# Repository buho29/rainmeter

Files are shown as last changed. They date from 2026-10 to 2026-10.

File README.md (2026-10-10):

# Zigbee Tipping Bucket Rain Gauge for Home Assistant

> 🇪🇸 [Versión en español](README%20es.md)
>
> 🖨️ **Download the print files on [MakerWorld](https://makerworld.com/es/models/3406401-rainmeter-zigbee-rain-gauge-for-home-assistant)**

A DIY tipping bucket rain gauge in Fusion 360, printed in ASA and read by a **Zigbee door sensor** (magnet + reed switch) integrated into Home Assistant. It shares its frame with a **Stevenson screen** that shelters a temperature, humidity and pressure sensor, and it has a plate rain sensor on the side.

<p align="center">
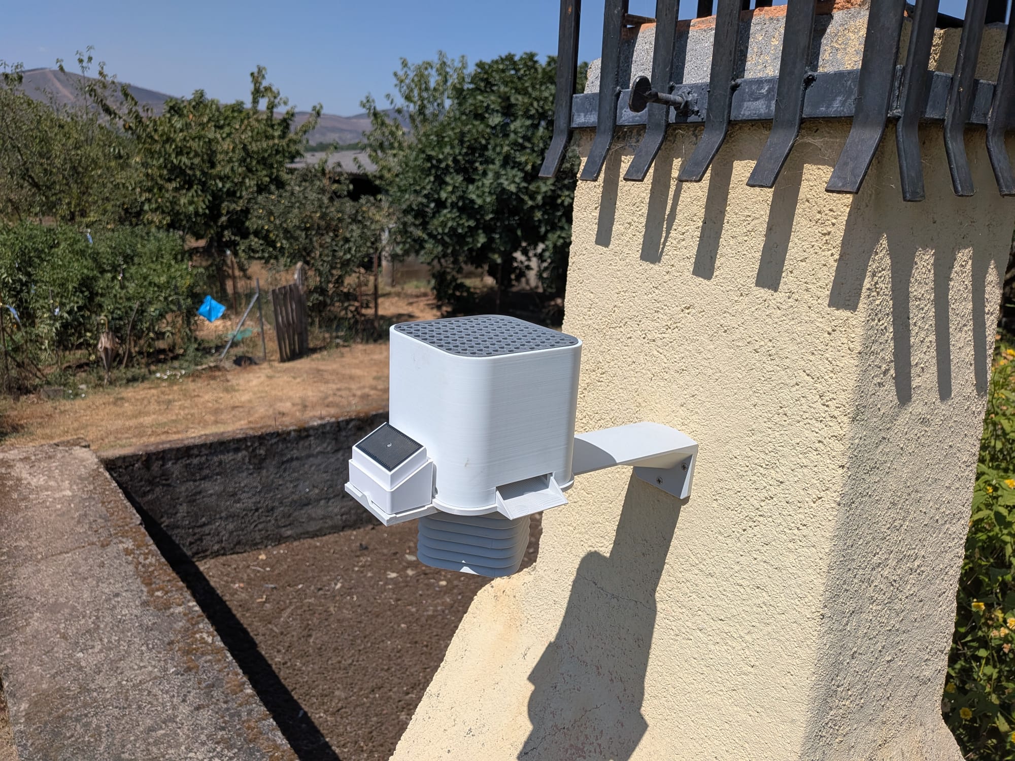
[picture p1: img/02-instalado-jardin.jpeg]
Installed rain gauge
  
</p>

## Features

| Parameter | Value |
|---|---|
| Collection area | **100 cm²** (square opening with R20 mm corners, side ≈ 101.7 mm) |
| Volume per tip | **5 ml** → **0.5 mm** of rain |
| Tip sensor | Zigbee door sensor (`binary_sensor.puerta_1_contact`), no ESP needed |
| Material | ASA (UV and weather resistant) |
| Bucket axle | Ø2.5 mm stainless steel, seated directly in the ASA |
| End stops | M3 screws threaded into the part, they set the tipping angle |
| Magnet | Ø3 × 2 mm neodymium magnet on the tipping bucket, triggers the door sensor's reed switch |
| Extras | Stevenson screen, plate rain sensor, storm warning |

## Zigbee sensors used

| | Sensor | Purpose | Link |
|---|---|---|---|
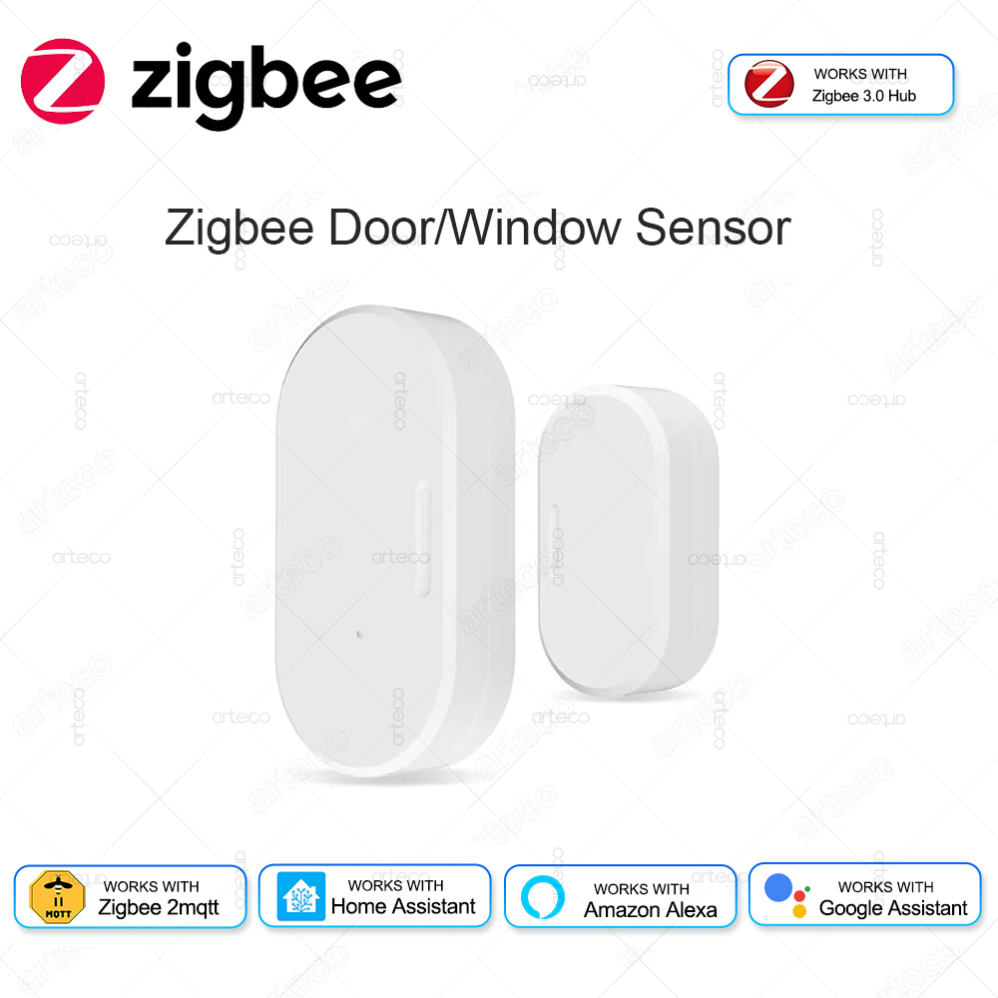
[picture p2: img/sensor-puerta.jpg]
Door sensor
|  | Door sensor (reed) | Counts the bucket tips | [AliExpress](https://es.aliexpress.com/item/1005007307128850.html) |
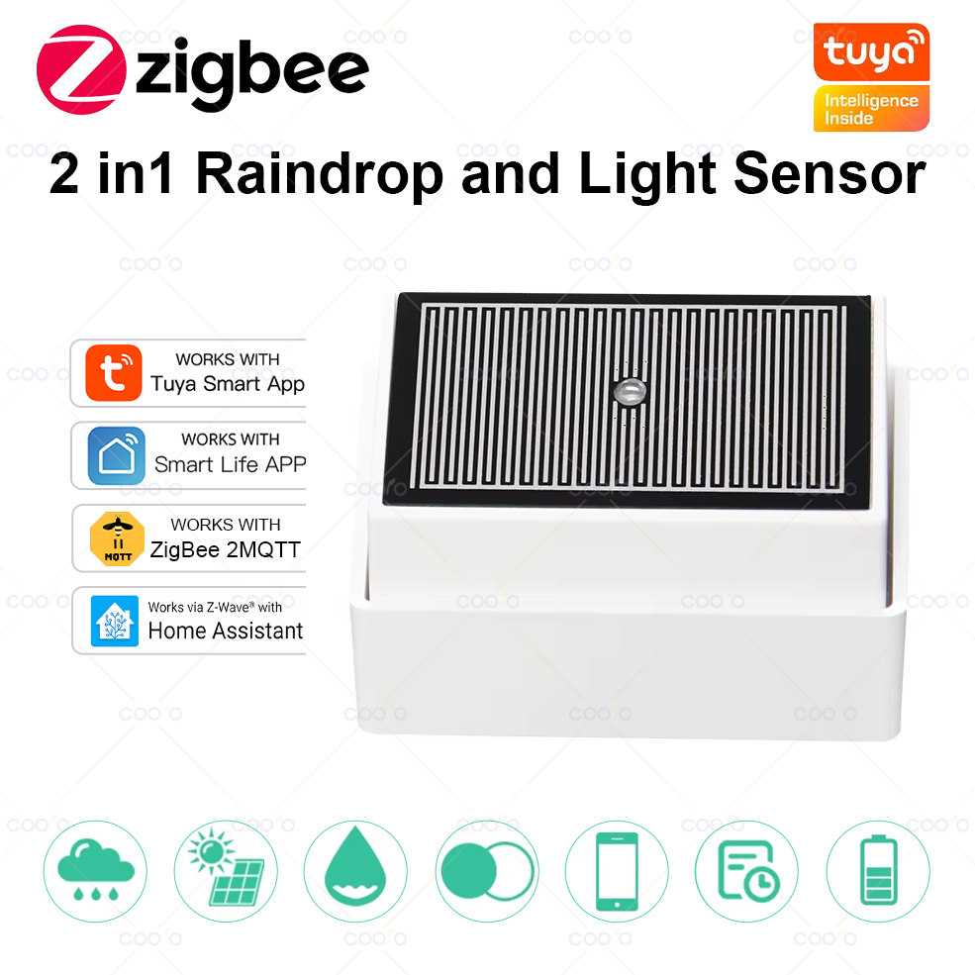
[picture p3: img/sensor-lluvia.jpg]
Rain sensor
|  | Plate rain + light sensor (Tuya) | Detects rain and measures illuminance | [AliExpress](https://es.aliexpress.com/item/1005009511764724.html) ⚠️ **not recommended** |
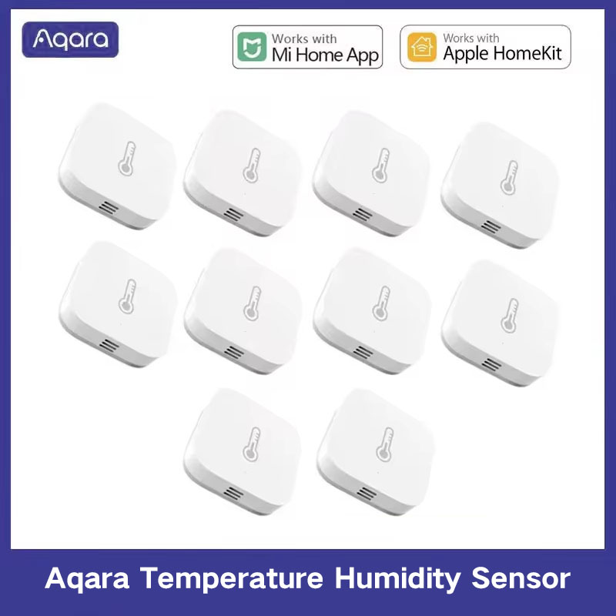
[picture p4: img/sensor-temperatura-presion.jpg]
Aqara sensor
|  | Aqara temperature / humidity / pressure | Inside the Stevenson screen | [AliExpress](https://es.aliexpress.com/item/1005007499860935.html) |

## Files

| File | Description |
|---|---|
| [MakerWorld](https://makerworld.com/es/models/3406401-rainmeter-zigbee-rain-gauge-for-home-assistant) | Published model, ready to print |
| [`rainmeter.yaml`](rainmeter.yaml) | Home Assistant package: counters, rain/flow sensors, `utility_meter`, pressure trend and storm warning |
| [`dashboard.yaml`](dashboard.yaml) | Weather station dashboard card |
| [`embudo.3mf`](embudo.3mf) | Print project (Bambu Studio) |
| [`3D source/`](3D%20source/) | Model sources: `pluviometro.f3z` (Fusion 360) and `pluviometro.step` |

## Home Assistant installation

1. In `configuration.yaml`:

   ```yaml
   homeassistant:
     packages: !include_dir_named packages
   ```

2. Copy `rainmeter.yaml` to `<config>/packages/rainmeter.yaml`.
3. Change the `entity_id`s to match your hardware (`binary_sensor.puerta_1_contact`, `sensor.termometro_exterior_pressure`).
4. Restart HA (or reload `counter`, `input_datetime` and `template`; `utility_meter` needs a restart).
5. Paste `dashboard.yaml` into a manual card. It uses custom cards from HACS (`mushroom`, `mini-graph-card`, `expander-card`, `card-mod`).

### Main entities

| Entity | Description |
|---|---|
| `counter.rainmeter_tip_count_calibration` | Tips in the calibration session (reset by hand) |
| `counter.rainmeter_tip_count_total` | Total tips (never reset, feeds the `utility_meter`s) |
| `sensor.rainmeter_rain_accumulated` | Rain accumulated in the session (mm) |
| `sensor.rainmeter_flow_rate` | Average flow over the session (mL/s) |
| `sensor.rainmeter_rain_rate_hourly` | Rain in the current hour (mm/h) |
| `sensor.rainmeter_rain_rate_daily` | Rain in the current day (mm/24h) |
| `sensor.rainmeter_pressure_trend` | Pressure trend (hPa/h) |

### Conversions

- Tips → mm: `tips × 0.5`
- mm → mL (100 cm²): `mm × 10`
- mL/s → mm/h (100 cm²): `mL/s × 360`

## Calibrating the end-stop screws

You need a 5 ml syringe and a 100 ml measure.

> **Level the rain gauge before calibrating.** If it is tilted, one side tips earlier than the other and the calibration is wrong.

### 1. Adjust each side (4.6 ml)
1. Let the bucket rest on one side.
2. With the syringe, slowly add **4.6 ml** to the upper bucket.
3. Adjust the M3 end-stop screw on that side until the bucket tips right at 4.6 ml. If it tips too early or too late, turn the screw and repeat.
4. Do the same on the other side.

It is calibrated at 4.6 ml instead of 5 ml for two reasons:
- Water keeps coming in while the bucket is tipping.
- A few drops always stay stuck in the bucket after each tip. The design tries to minimise them, but they never go away completely.

Together, each tip ends up being about 5 ml, which is what `rainmeter.yaml` counts.

### 2. Validate with 100 ml
1. Reset the counter with the **Resetear contador** (reset counter) button on the dashboard (`counter.rainmeter_tip_count_calibration`).
2. Pour **100 ml very slowly** into the gauge opening.
3. It should read **20 tips** (accumulated = 10 mm).
4. The **Flujo** (flow) sensor (`sensor.rainmeter_flow_rate`) must not go above **6 ml/s**. At 12 ml/s about 15 % is lost (see [Flow test](#flow-test)).

If you get more than 20 tips, each tip holds less than 5 ml: adjust the stops so it tips with a little more water. If you get fewer, do the opposite. Repeat until you get 20.

### 3. Check again in the final installation
Once it is mounted in place, level it again and use the syringe to check that each side still tips at 4.6 ml, or at whatever volume worked in the 100 ml test. Screwing on the bracket can leave it slightly tilted and shift the tipping point. If one side has changed, readjust its end-stop screw.

## Design notes

### Tipping bucket
- Double V-shaped bucket (1.6 mm wall) on a **Ø2.5 mm stainless steel axle**, with **M3 screw end stops** threaded into the part that set the tipping angle.
- Calibration target, the same one `rainmeter.yaml` uses: **5 ml per tip = 0.5 mm** of rain over 100 cm².
- **Axle height:** higher = cleaner tip but needs more angle; very low = "twitchy" tipping.
- **Chamfer** towards the axle: moves the water's centre of gravity away and makes it tip earlier. Bucket **depth** was the most effective lever to increase volume.
- Balance at the tipping point: `m_water · d_water = m_body · d_body` (water centre of gravity measured in Fusion with *Boundary Fill*).
- With little angular travel after tipping, drops stay trapped; at ~20° hardly any remain.

### Water inlet
- The central wedge was removed: it catapulted the water out. It is better for water to fall into the corner of the bucket.
- Wide-mesh leaf guard (fine meshes splash and clog).

### Asymmetric counting (solved)
When tipping to one side it counted twice, and to the other side once (or not at all). It was not software: the sensor was not centred relative to the two magnet positions. **Moving the sensor 13 mm** fixed it.

That is why `rainmeter.yaml` has **no debounce**. The `Rainmeter - Increment tip counters` automation fires on every `off → on` change of `binary_sensor.puerta_1_contact`, adds one to both counters and uses `mode: queued` so quick consecutive tips are not lost.

### Flow test
Measured with `sensor.rainmeter_flow_rate`, which computes `(tips × 5) / seconds`. The seconds run from the first tip of the session (`input_datetime.rainmeter_flow_start_time`) to the last one. It is an average flow meant for calibration, not an instantaneous rain rate. To convert to mm/h: `mL/s × 360`.

- 6 ml/s (≈ 2160 mm/h) → correct reading (200 ml out of 200 ml).
- 12 ml/s (≈ 4320 mm/h) → ~15 % loss.
- Both are far above any real rainfall (records are around 300 mm/h over 1 min).

### Storm warning
A `derivative` sensor (`sensor.rainmeter_pressure_trend`, 20 min window) computes the pressure trend in hPa/h from `sensor.termometro_exterior_pressure`. The `Rainmeter - Storm Warning` automation:

- Fires when the trend drops below **−3 hPa/h** (storm approaching) or rises above **+3 hPa/h** (gust front already arriving), held for **2 min**.
- Has a **90 min cooldown**, so the pressure recovering after a spike does not count as a new storm.
- Sends `notify.notify` and a `persistent_notification` with a fixed `notification_id` (it updates instead of piling up).

**Why a 20 min window:** the derivative was simulated over 10 days of pressure history, including the storm on 03/10/2026. With 30 min the trend barely reached +3.2 hPa/h and did not hold for 2 min, so it **would not have warned**. With 20 min it would have warned about 14 min before the heavy rain, with no false alarms in those 10 days. With 15 min or less, the sensor's 0.1 hPa steps already cause false alarms.

### Zigbee sensor care
- Door sensors are not waterproof: keep the reed switch and magnet away from water.
- Zigbee latency and battery drain during very heavy rain.

## Gallery

### Installed

<table>
  <tr>
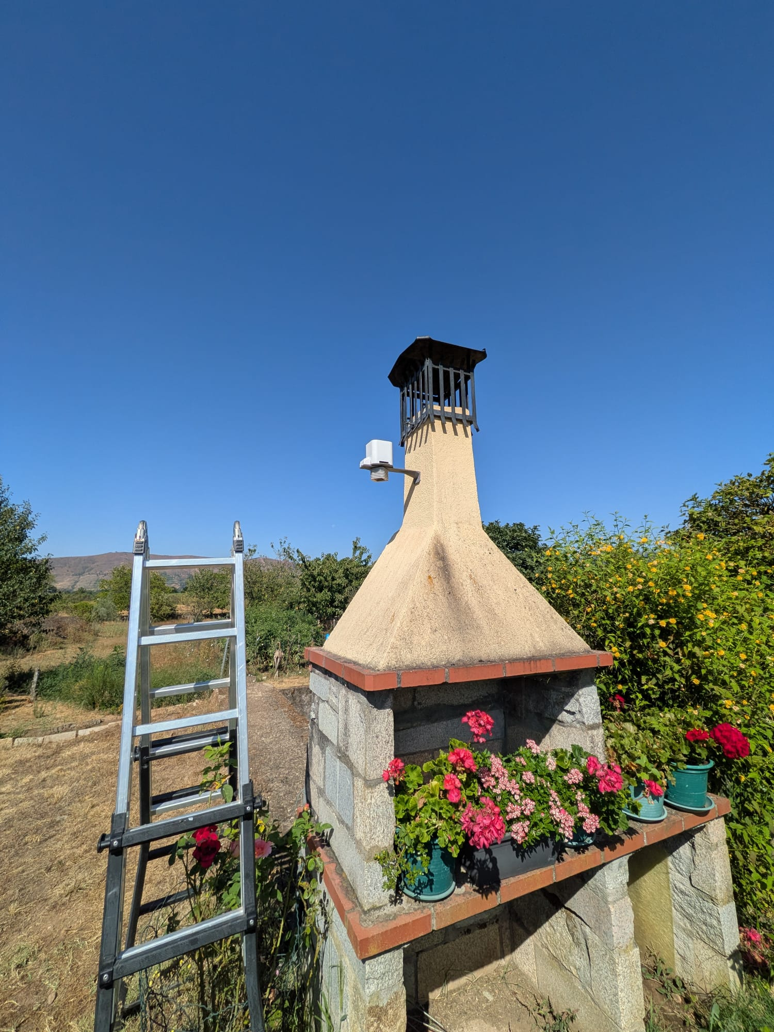
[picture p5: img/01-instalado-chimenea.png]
Installed on the chimney
    <td></td>
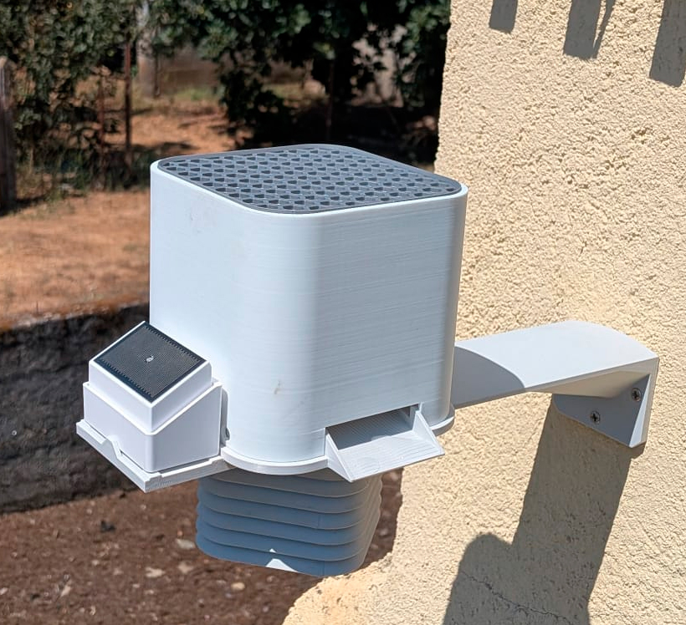
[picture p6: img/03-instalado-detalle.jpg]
Installed, close-up
    <td></td>
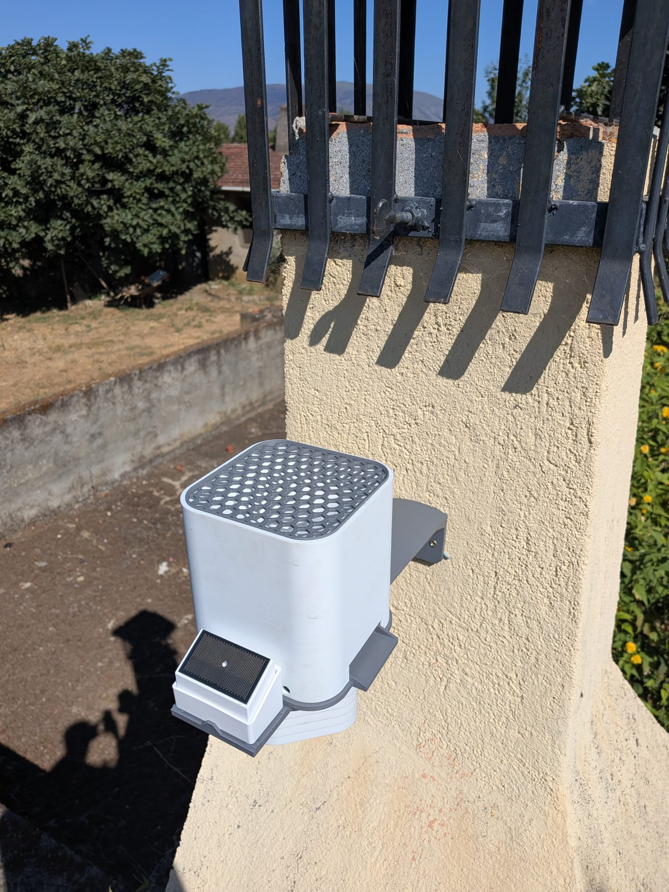
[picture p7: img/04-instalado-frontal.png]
View from above
    <td></td>
  </tr>
  <tr>
    <td align="center" valign="top" width="33%">Overview</td>
    <td align="center" valign="top" width="33%">Close-up</td>
    <td align="center" valign="top" width="33%">View from above</td>
  </tr>
  <tr>
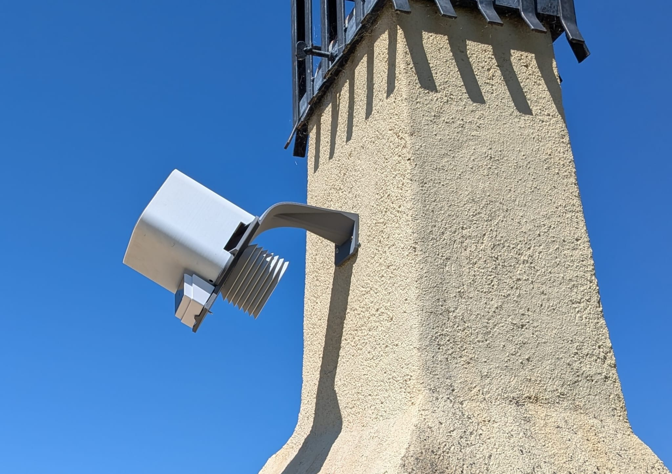
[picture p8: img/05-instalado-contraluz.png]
From below
    <td></td>
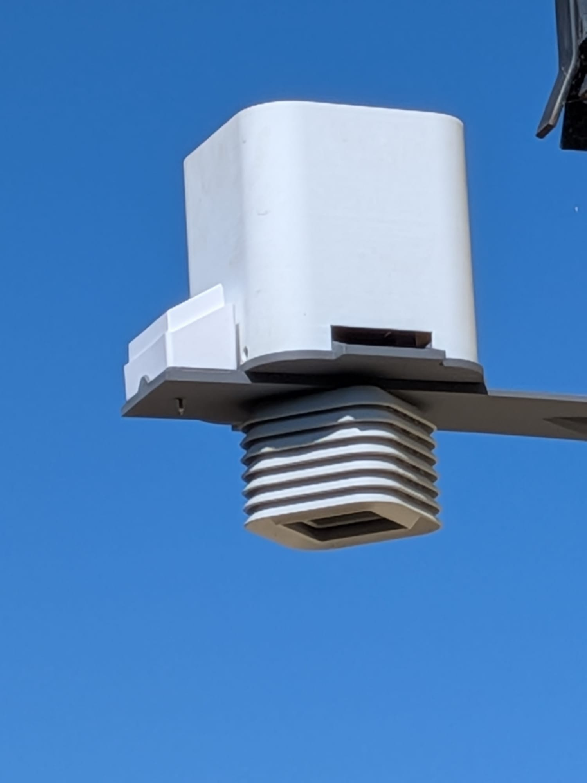
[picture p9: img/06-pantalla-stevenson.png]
Stevenson screen
    <td></td>
    <td>Installed</td>
  </tr>
  <tr>
    <td align="center" valign="top" width="33%">From below<br><sub>The arm in this version was printed in PLA and didn't last even 3 h in the sun</sub></td>
    <td align="center" valign="top" width="33%">Stevenson screen</td>
    <td align="center" valign="top" width="33%">Installed</td>
  </tr>
</table>

### Assembly

<table>
  <tr>
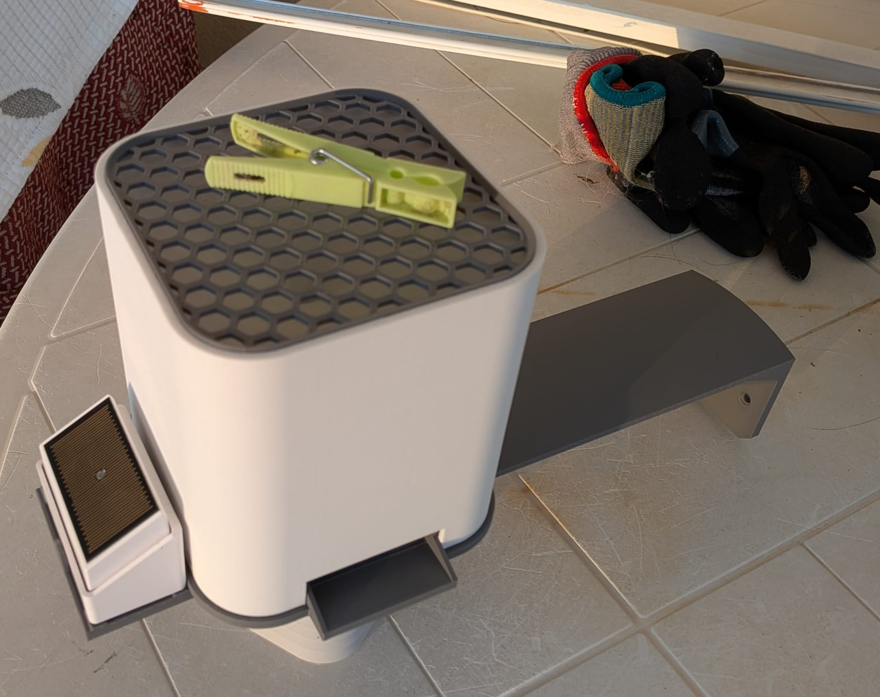
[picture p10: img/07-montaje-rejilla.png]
Leaf guard
    <td></td>
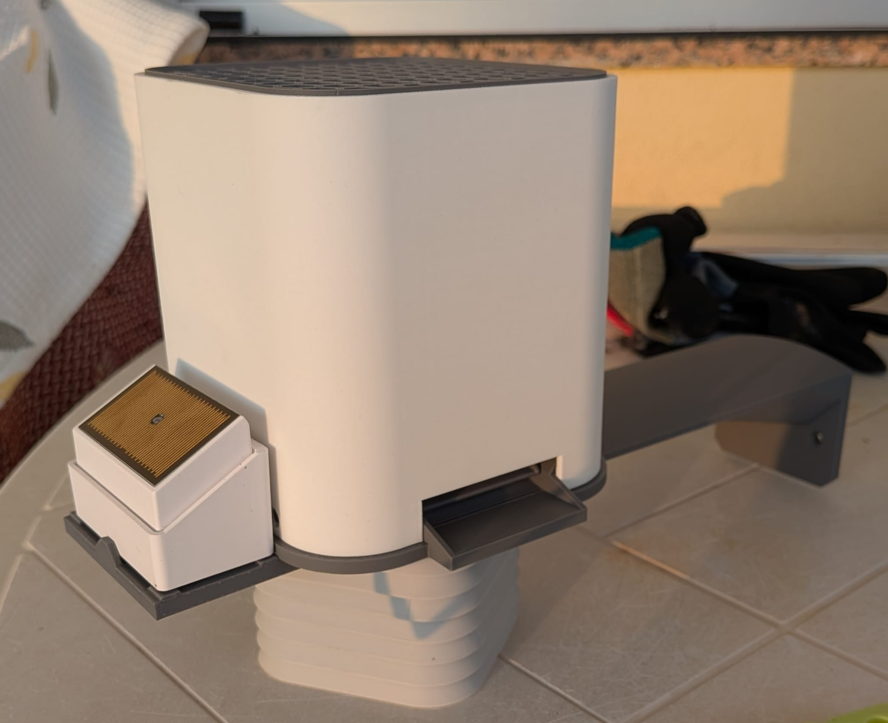
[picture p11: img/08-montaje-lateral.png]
Side view
    <td></td>
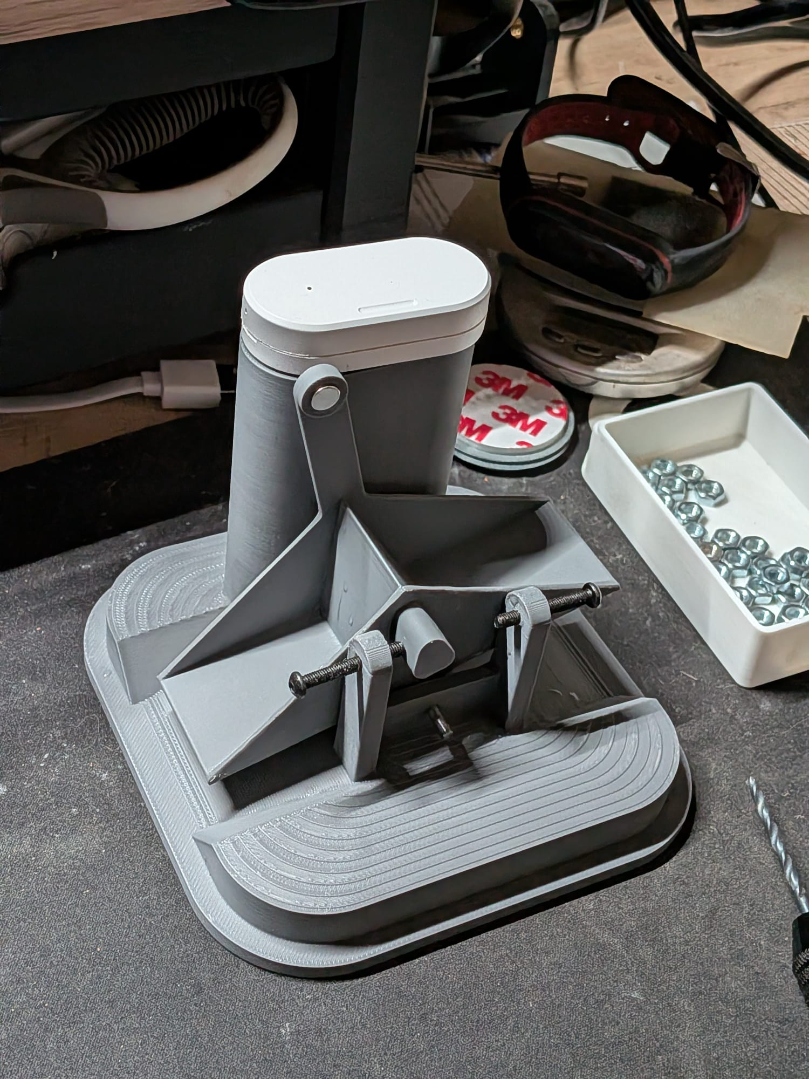
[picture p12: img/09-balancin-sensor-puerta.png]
Tipping bucket and door sensor
    <td></td>
  </tr>
  <tr>
    <td align="center">Leaf guard</td>
    <td align="center">Side view</td>
    <td align="center">Tipping bucket, end stops and door sensor</td>
  </tr>
</table>

### 3D design (Fusion 360)

<table>
  <tr>
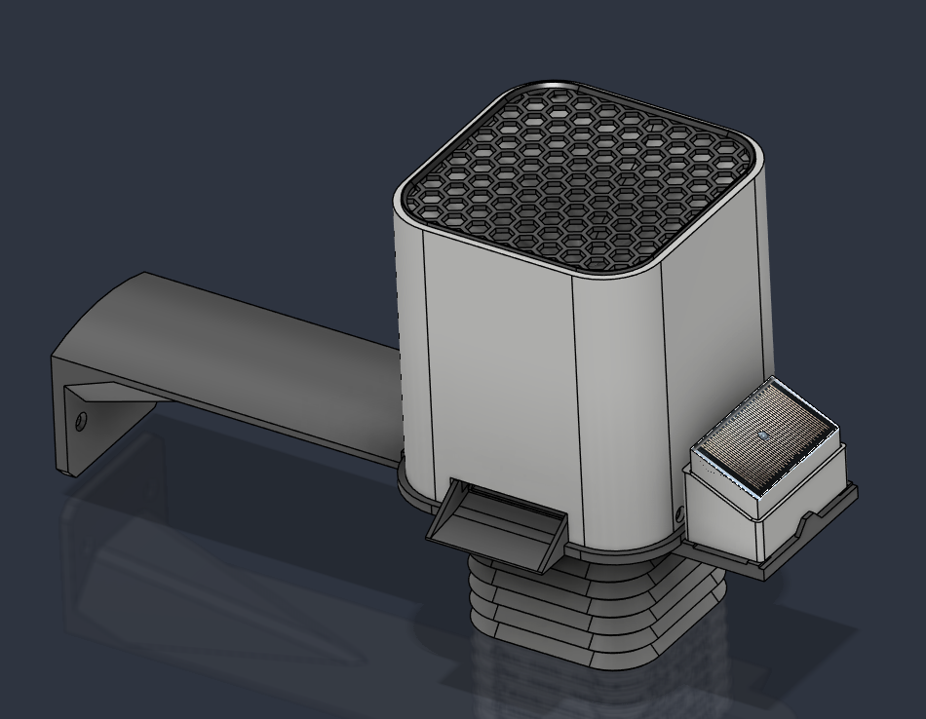
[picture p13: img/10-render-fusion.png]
Full render
    <td></td>
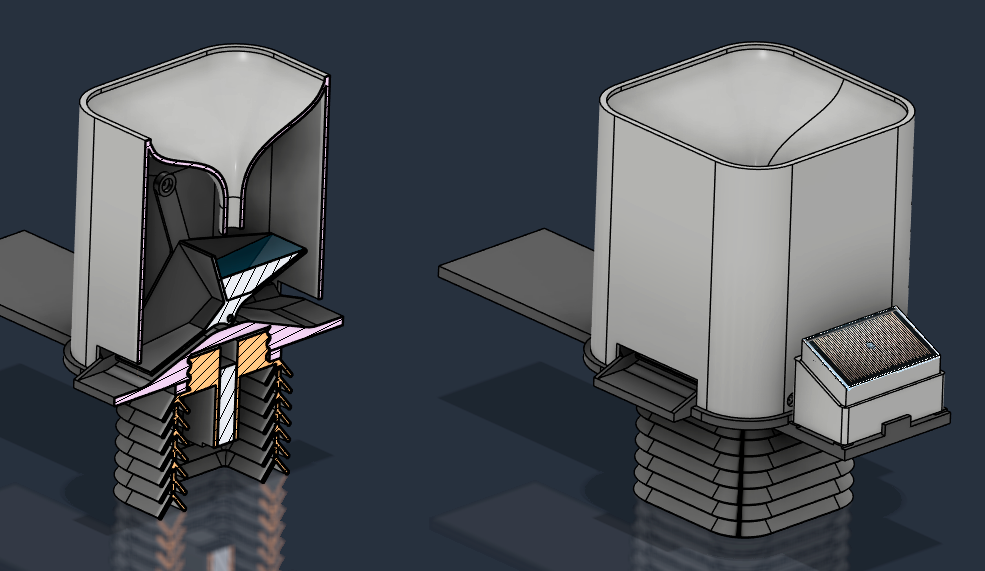
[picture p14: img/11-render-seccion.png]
Funnel and bucket cross-section
    <td></td>
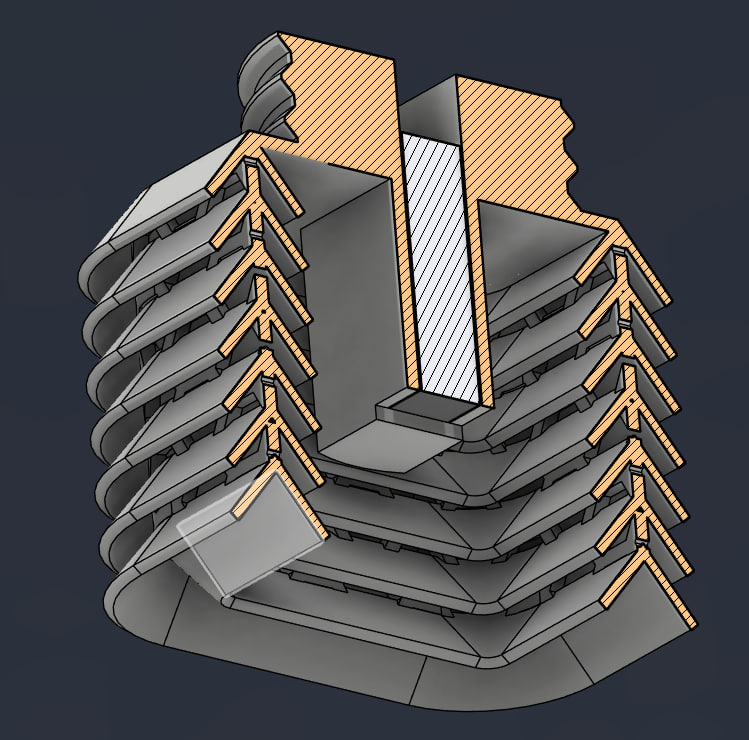
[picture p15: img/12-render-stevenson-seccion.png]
Stevenson screen cross-section
    <td></td>
  </tr>
  <tr>
    <td align="center">Full render</td>
    <td align="center">Cross-section: funnel and bucket</td>
    <td align="center">Cross-section: Stevenson screen</td>
  </tr>
</table>

### Home Assistant

<p align="center">
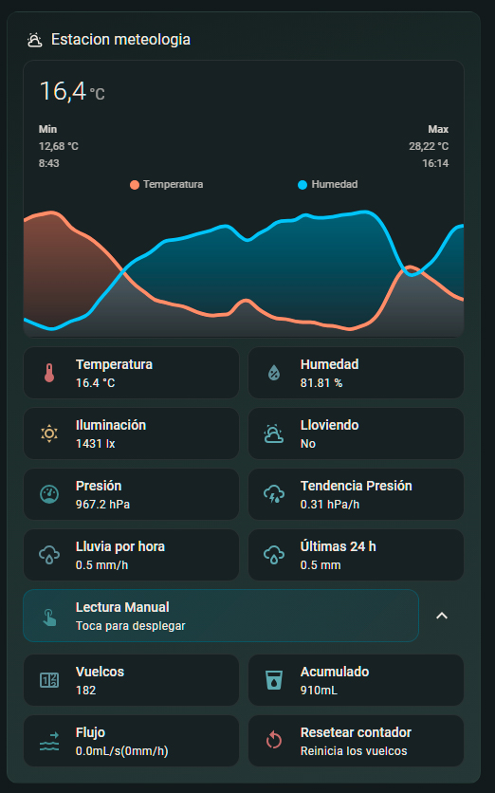
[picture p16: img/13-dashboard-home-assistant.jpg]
Home Assistant dashboard
  
</p>

## Sources of inspiration

- **Thread:** [Fusion 360 Thread Profiles for 3D Printing](https://makerworld.com/es/models/2567099-fusion-360-thread-profiles-for-3d-printing#profileId-2829308). Thread profiles for Fusion 360 tuned for 3D printing.
- [Rain Gauge](https://makerworld.com/es/models/1366151-rain-gauge): the idea of an adjustable tipping bucket with calibration screws came from here.
- [Tipping Bucket Rain Gauge](https://makerworld.com/es/models/1451114-tipping-bucket-rain-gauge): 100 cm² rain gauge with 5 ml per tip (0.5 mm).
- [LTB Weather Station](https://www.thingiverse.com/thing:2849562) (Thingiverse): 3D-printable weather station.

This rain gauge is an original design; these models were used only as reference.

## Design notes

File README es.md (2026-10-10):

# Pluviómetro basculante Zigbee para Home Assistant

> 🇬🇧 [English version](README.md)
>
> 🖨️ **Descarga los archivos de impresión en [MakerWorld](https://makerworld.com/es/models/3406401-rainmeter-zigbee-rain-gauge-for-home-assistant)**

Pluviómetro DIY de balancín (*tipping bucket*) diseñado en Fusion 360, impreso en ASA y leído con un **sensor de puerta Zigbee** (imán + reed) integrado en Home Assistant. Comparte estructura con una **pantalla Stevenson** que protege un sensor de temperatura, humedad y presión, y lleva un sensor de lluvia de placa en el lateral.

<p align="center">
  Pluviómetro instalado
</p>

## Características

| Parámetro | Valor |
|---|---|
| Área de captación | **100 cm²** (boca cuadrada R20 mm, lado ≈ 101,7 mm) |
| Volumen por vuelco | **5 ml** → **0,5 mm** de lluvia |
| Sensor de vuelcos | Sensor de puerta Zigbee (`binary_sensor.puerta_1_contact`), sin ESP |
| Material | ASA (resistente a UV e intemperie) |
| Eje del balancín | Acero inoxidable Ø2,5 mm alojado directamente en el ASA |
| Topes | Tornillos M3 que se atornillan en la pieza y regulan el ángulo de disparo |
| Imán | Imán de neodimio de Ø3 × 2 mm en el balancín, activa el reed del sensor de puerta |
| Extras | Pantalla Stevenson, sensor de lluvia de placa, alerta de tormenta |

## Sensores Zigbee usados

| | Sensor | Uso | Enlace |
|---|---|---|---|
| Sensor de puerta | Sensor de puerta (reed) | Cuenta los vuelcos del balancín | [AliExpress](https://es.aliexpress.com/item/1005007307128850.html) |
| Sensor de lluvia | Sensor de lluvia de placa + luz (Tuya) | Detecta lluvia y mide la iluminación | [AliExpress](https://es.aliexpress.com/item/1005009511764724.html) ⚠️ **no lo recomiendo** |
| Sensor Aqara | Aqara temperatura / humedad / presión | Dentro de la pantalla Stevenson | [AliExpress](https://es.aliexpress.com/item/1005007499860935.html) |

## Archivos

| Archivo | Descripción |
|---|---|
| [MakerWorld](https://makerworld.com/es/models/3406401-rainmeter-zigbee-rain-gauge-for-home-assistant) | Modelo publicado, listo para imprimir |
| [`rainmeter.yaml`](rainmeter.yaml) | *Package* de Home Assistant: contadores, sensores de lluvia/flujo, `utility_meter`, tendencia de presión y alerta de tormenta |
| [`dashboard.yaml`](dashboard.yaml) | Tarjeta de dashboard de la estación meteorológica |
| [`embudo.3mf`](embudo.3mf) | Proyecto de impresión (Bambu Studio) |
| [`3D source/`](3D%20source/) | Fuentes del modelo: `pluviometro.f3z` (Fusion 360) y `pluviometro.step` |

## Instalación en Home Assistant

1. En `configuration.yaml`:

   ```yaml
   homeassistant:
     packages: !include_dir_named packages
   ```

2. Copia `rainmeter.yaml` a `<config>/packages/rainmeter.yaml`.
3. Ajusta los `entity_id` a tu hardware (`binary_sensor.puerta_1_contact`, `sensor.termometro_exterior_pressure`).
4. Reinicia HA (o recarga `counter`, `input_datetime` y `template`; `utility_meter` necesita reinicio).
5. Pega `dashboard.yaml` en una tarjeta manual. Usa tarjetas personalizadas de HACS (`mushroom`, `mini-graph-card`, `expander-card`, `card-mod`).

### Entidades principales

| Entidad | Descripción |
|---|---|
| `counter.rainmeter_tip_count_calibration` | Vuelcos de la sesión de calibración (se resetea a mano) |
| `counter.rainmeter_tip_count_total` | Vuelcos totales (nunca se resetea, alimenta los `utility_meter`) |
| `sensor.rainmeter_rain_accumulated` | Lluvia acumulada en la sesión (mm) |
| `sensor.rainmeter_flow_rate` | Flujo medio de la sesión (mL/s) |
| `sensor.rainmeter_rain_rate_hourly` | Lluvia de la hora actual (mm/h) |
| `sensor.rainmeter_rain_rate_daily` | Lluvia del día actual (mm/24h) |
| `sensor.rainmeter_pressure_trend` | Tendencia de presión (hPa/h) |

### Conversiones

- Vuelcos → mm: `vuelcos × 0,5`
- mm → mL (100 cm²): `mm × 10`
- mL/s → mm/h (100 cm²): `mL/s × 360`

## Calibración de los tornillos de tope

Necesitas una jeringuilla de 5 ml y una medida de 100 ml.

> **Nivela el pluviómetro antes de calibrar.** Si está inclinado, un lado vuelca antes que el otro y la calibración no vale.

### 1. Ajustar cada lado (4,6 ml)
1. Deja el balancín apoyado en un lado.
2. Con la jeringuilla, echa **4,6 ml** poco a poco en la cazoleta de arriba.
3. Ajusta el tornillo M3 del tope de ese lado hasta que vuelque justo al llegar a 4,6 ml. Si vuelca antes o después, gira el tornillo y repite.
4. Haz lo mismo con el otro lado.

Se calibra a 4,6 ml y no a 5 ml por dos motivos:
- Mientras el balancín gira sigue entrando agua.
- En la cazoleta siempre quedan algunas gotas pegadas después de cada vuelco. El diseño intenta minimizarlas, pero no desaparecen del todo.

Con eso, cada vuelco acaba siendo de unos 5 ml, que es lo que cuenta `rainmeter.yaml`.

### 2. Validar con 100 ml
1. Resetea el contador con el botón **Resetear contador** del dashboard (`counter.rainmeter_tip_count_calibration`).
2. Vierte **100 ml muy despacio** en la boca del pluviómetro.
3. Debe marcar **20 vuelcos** (Acumulado = 10 mm).
4. El sensor **Flujo** (`sensor.rainmeter_flow_rate`) no debe pasar de **6 ml/s**. A 12 ml/s se pierde ~15 % (ver [Prueba de caudal](#prueba-de-caudal)).

Si salen más de 20 vuelcos, cada vuelco lleva menos de 5 ml: ajusta los topes para que vuelque con un poco más de agua. Si salen menos, al revés. Repite hasta que salgan 20.

### 3. Comprobar de nuevo en la instalación final
Cuando esté montado en su sitio, nivélalo otra vez y comprueba con la jeringuilla que cada lado sigue volcando con 4,6 ml, o con el volumen que te haya salido bien en la prueba de 100 ml. Al atornillar el soporte puede quedar algo inclinado y cambiar el punto de vuelco. Si un lado ha cambiado, reajusta su tornillo de tope.

## Notas de diseño

### Balancín
- Doble cazoleta en V (pared 1,6 mm) sobre un **eje de acero inoxidable de Ø2,5 mm**, con **topes de tornillos M3** que se atornillan en la pieza y fijan el ángulo de disparo.
- Objetivo de calibración, el mismo que usa `rainmeter.yaml`: **5 ml por vuelco = 0,5 mm** de lluvia sobre 100 cm².
- **Altura del eje:** más alto = vuelco más franco pero necesita más ángulo; muy bajo = disparo "nervioso".
- **Chaflán** hacia el eje: aleja el CG del agua y hace que dispare antes. La **profundidad** de la cazoleta fue la palanca más eficiente para subir volumen.
- Equilibrio en el disparo: `m_agua · d_agua = m_cuerpo · d_cuerpo` (CG del agua medido en Fusion con *Boundary Fill*).
- Con poco recorrido angular tras el disparo quedan gotas retenidas; con ~20° apenas quedan.

### Entrada del agua
- Se eliminó la cuña central: catapultaba el agua fuera. Mejor que caiga en la esquina de la cazoleta.
- Rejilla antihojas de malla ancha (las finas salpican y se obstruyen).

### Conteo asimétrico (resuelto)
Al bascular a un lado contaba 2 veces y al otro 1 (o 0). No era software: el sensor no quedaba centrado respecto a las dos posiciones del imán. **Desplazar el sensor 13 mm** lo solucionó.

Por eso `rainmeter.yaml` **no lleva debounce**. La automatización `Rainmeter - Increment tip counters` salta con cada cambio `off → on` de `binary_sensor.puerta_1_contact`, suma uno a los dos contadores y usa `mode: queued` para no perder vuelcos seguidos.

### Prueba de caudal
Se mide con `sensor.rainmeter_flow_rate`, que calcula `(vuelcos × 5) / segundos`. Los segundos van desde el primer vuelco de la sesión (`input_datetime.rainmeter_flow_start_time`) hasta el último. Es un flujo medio, pensado para calibrar, no una tasa de lluvia instantánea. Para pasarlo a mm/h: `mL/s × 360`.

- 6 ml/s (≈ 2160 mm/h) → lectura correcta (200 ml de 200 ml).
- 12 ml/s (≈ 4320 mm/h) → ~15 % de pérdida.
- Ambos muy por encima de cualquier lluvia real (récords de ~300 mm/h en 1 min).

### Alerta de tormenta
Un sensor `derivative` (`sensor.rainmeter_pressure_trend`, ventana de 20 min) calcula la tendencia de presión en hPa/h a partir de `sensor.termometro_exterior_pressure`. La automatización `Rainmeter - Storm Warning`:

- Salta cuando la tendencia baja de **−3 hPa/h** (tormenta acercándose) o sube de **+3 hPa/h** (frente de racha ya llegando), mantenida **2 min**.
- Tiene un **enfriamiento de 90 min**, para que la recuperación de la presión tras un pico no cuente como una tormenta nueva.
- Envía `notify.notify` y una `persistent_notification` con `notification_id` fijo (se actualiza en vez de acumularse).

**Por qué 20 min de ventana:** se simuló la derivada con 10 días de historial de presión, que incluían la tormenta del 03/10/2026. Con 30 min la tendencia apenas llegó a +3,2 hPa/h y no se mantuvo 2 min, así que **no habría avisado**. Con 20 min habría avisado unos 14 min antes de la lluvia fuerte, sin ninguna falsa alarma en esos 10 días. Con 15 min o menos, los escalones de 0,1 hPa del sensor ya generan falsas alarmas.

### Cuidados con el sensor Zigbee
- Los sensores de puerta no son estancos: aislar reed e imán del agua.
- Latencia Zigbee y consumo de batería con lluvia muy intensa.

## Galería

### Instalado

<table>
  <tr>
    <td>Instalado en la chimenea</td>
    <td>Detalle instalado</td>
    <td>Vista desde arriba</td>
  </tr>
  <tr>
    <td align="center" valign="top" width="33%">Vista general</td>
    <td align="center" valign="top" width="33%">Detalle</td>
    <td align="center" valign="top" width="33%">Vista desde arriba</td>
  </tr>
  <tr>
    <td>Desde abajo</td>
    <td>Pantalla Stevenson</td>
    <td>Instalado</td>
  </tr>
  <tr>
    <td align="center" valign="top" width="33%">Desde abajo<br><sub>El brazo de esta versión se imprimió en PLA y no duró ni 3 h al sol</sub></td>
    <td align="center" valign="top" width="33%">Pantalla Stevenson</td>
    <td align="center" valign="top" width="33%">Instalado</td>
  </tr>
</table>

### Montaje

<table>
  <tr>
    <td>Rejilla antihojas</td>
    <td>Vista lateral</td>
    <td>Balancín y sensor de puerta</td>
  </tr>
  <tr>
    <td align="center">Rejilla antihojas</td>
    <td align="center">Vista lateral</td>
    <td align="center">Balancín, topes y sensor de puerta</td>
  </tr>
</table>

### Diseño 3D (Fusion 360)

<table>
  <tr>
    <td>Render completo</td>
    <td>Sección embudo y balancín</td>
    <td>Sección pantalla Stevenson</td>
  </tr>
  <tr>
    <td align="center">Render completo</td>
    <td align="center">Sección: embudo y balancín</td>
    <td align="center">Sección: pantalla Stevenson</td>
  </tr>
</table>

### Home Assistant

<p align="center">
  Dashboard en Home Assistant
</p>

## Fuentes de inspiración

- **Rosca:** [Fusion 360 Thread Profiles for 3D Printing](https://makerworld.com/es/models/2567099-fusion-360-thread-profiles-for-3d-printing#profileId-2829308). Perfiles de rosca para Fusion 360 pensados para impresión 3D.
- [Rain Gauge](https://makerworld.com/es/models/1366151-rain-gauge): de aquí viene la idea del balancín regulable con tornillos de calibración.
- [Tipping Bucket Rain Gauge](https://makerworld.com/es/models/1451114-tipping-bucket-rain-gauge): pluviómetro de 100 cm² y 5 ml por vuelco (0,5 mm).
- [LTB Weather Station](https://www.thingiverse.com/thing:2849562) (Thingiverse): estación meteorológica imprimible en 3D.

El diseño de este pluviómetro es propio; estos modelos solo sirvieron de referencia.

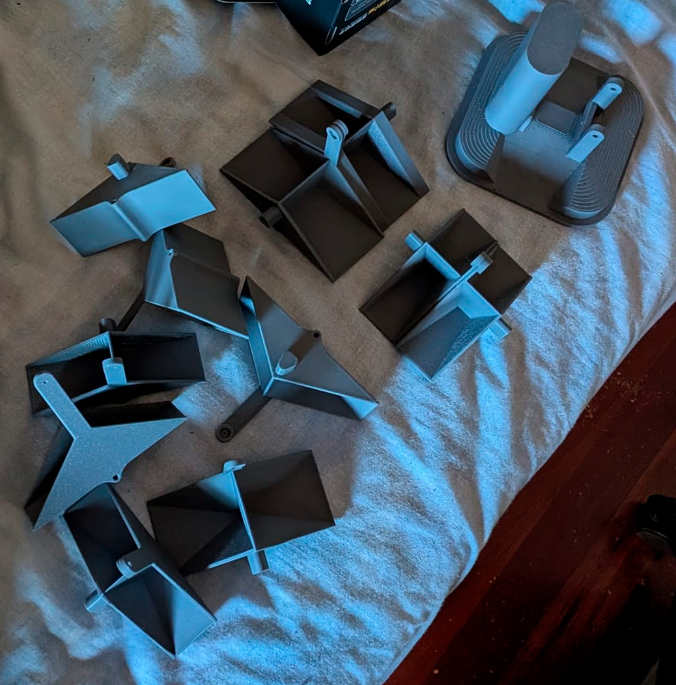
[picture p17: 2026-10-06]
img/balancin.jpg

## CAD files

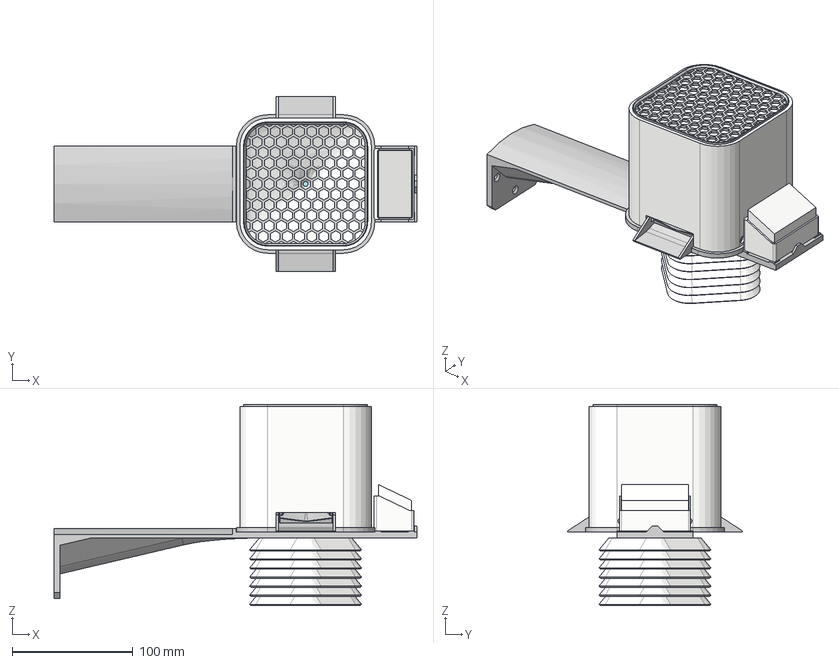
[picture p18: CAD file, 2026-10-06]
3D source/pluviometro.step
300.0 x 144.5 x 166.2 mm
embudo
cazueleta v2
sensor
sensor aqara
pluviometro

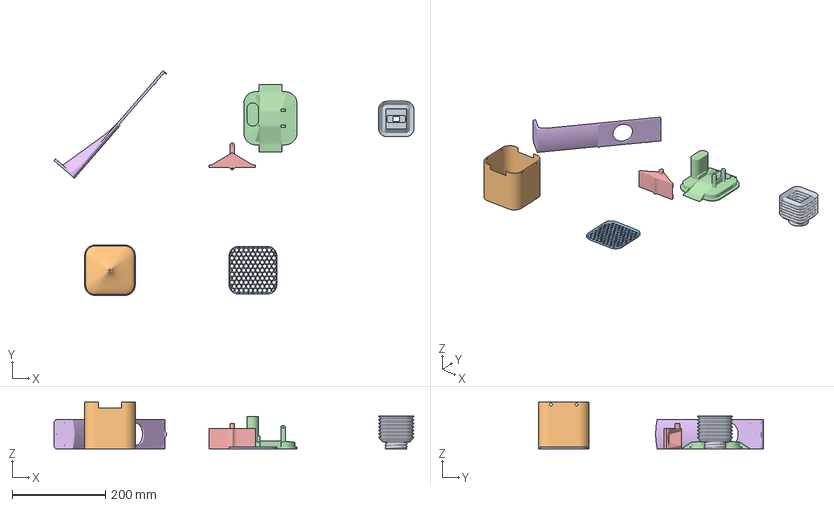
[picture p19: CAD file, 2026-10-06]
embudo.3mf
773.3 x 483.6 x 100.0 mm
pantalla termometro.step
embudo v61_1
embudo v61_2
base.step
cazueleta v2.step
soporte.step

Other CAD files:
3D source/pluviometro.f3z

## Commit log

2026-10-06 Pluviómetro basculante Zigbee: modelo 3D, package HA, dashboard y README
    [embudo.3mf, pluviometro.f3z, pluviometro.step]
2026-10-06 README en inglés, versión en español y sección de calibración
2026-10-06 Añadir imán de neodimio Ø3×2 mm a los README
2026-10-06 Fotos y enlaces corregidos de los sensores, y fuentes de inspiración
2026-10-06 Calibración: recomprobar los topes con jeringuilla en la instalación final
